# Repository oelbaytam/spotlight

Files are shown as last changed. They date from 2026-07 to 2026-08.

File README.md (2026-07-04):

# Spotlight

## What does it even do?
Spotlight is an [MQTT](https://learn.sparkfun.com/tutorials/introduction-to-mqtt/all) activated semi-high power LED (3.3-3.6V @715mA). It connects to MQTT Brokers (stay tuned for an MQTT discord bot!!) and uses the signal recieved to enable a PWM output to the LED. If I get it working correctly then there will be an enclosure with a way to focus the beam and some additional lenses to project imagery onto your wall or ceiling (think Bat-Signal). There are no physical inputs on the device so this is not a lamp.

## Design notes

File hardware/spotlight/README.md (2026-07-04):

# The Spotlight Hardware

Spotlight is my first attempt at SMD soldering, PCB design, Circuitry implementing an IC, and many other smaller things, so bear with any mistakes I make and feel free to contribute if you have hardware knowledge! \
(Make sure you teach me something if you submit a PR >:] )

## The Schematic and PCB
##### Fraud at a glance?
Schematic

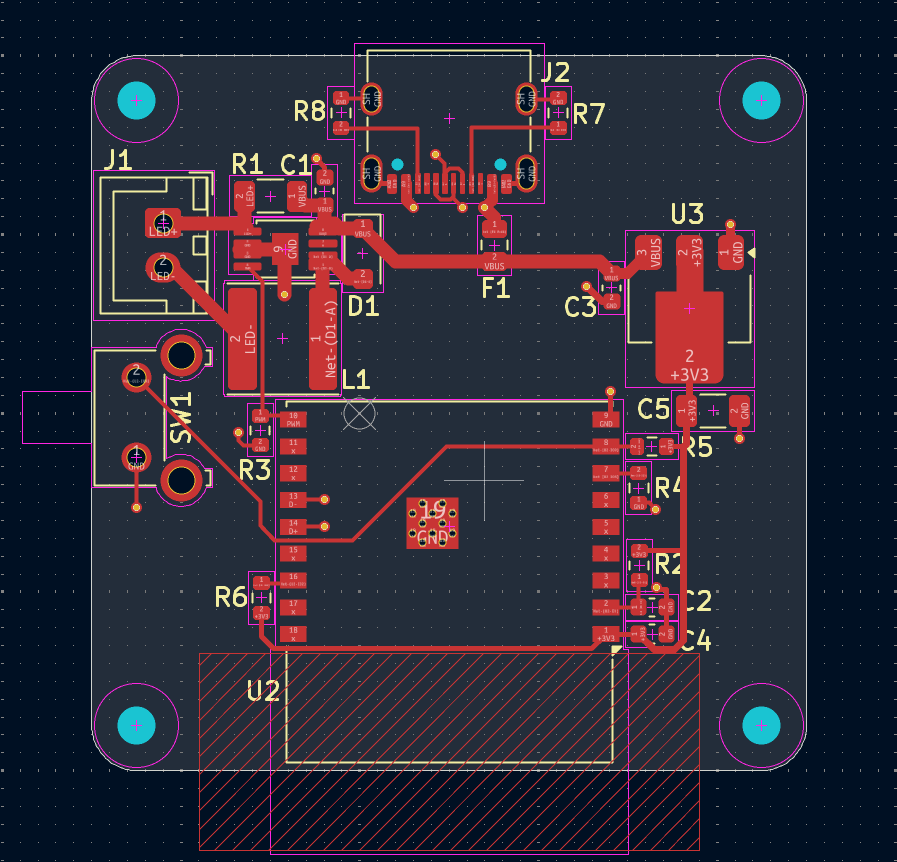
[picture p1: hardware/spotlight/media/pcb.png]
PCB


### The ICs
- AL8841MP-13 \
  A buck converter stepping down the 5V input to ~714mA constant current configured by the 0.14Ohm sense resistor. The LED I am using is 5W and expects 3.6V at 1.2A but in my testing it was plenty bright at 700mA@3.3V so I decided that it will live its life at 3W (heatsinks really drove up the price per unit).
- AMS1117-3.3 \
  LDO regulator that provides 3.3V to the MCU.
- ESP32-C3-WROOM-02-N4 \
  Before its a hardware project this was initially an embedded project so I could learn RTOS, MQTT, and the ESP-IDF development framework! I went with the WROOM because I only planned on using one GPIO pin. The C3 MINI was a bit cheaper but had a lot of much smaller pads that I wasn't confident I could reflow. (Probably could've added some extra pins but I didn't wanna overcomplicate any more.)

### The Cool Image on the Back?!
The picture is an item icon in DEADLOCK (I <3 Deadlock) called [Boundless Spirit](https://deadlock.wiki/Boundless_Spirit). It has nothing to do with the project, just a cool stamp I snatched. I put it through some image dithering so that it can work with the silkscreen, when I get the first PCBs in I will put a picture of it to show the real world result.

# Assembling the device
I don't know yet, but I have a plan that I will share with anyone who is new so assembly can be easy and cheap, I am pinching as many pennies as possible with this project. (Possibly will make a video?)

### Parts List

As of now, to get flashbanged, all you need is:
- The materials in the BOM (in the ./production folder but I would export it yourself)
- 3.3V LED that wont die taking 750mA (technically the size doesn't matter yet since I don't have an enclosure made.)
- JST XH-2 connector with a cable
- a Heatsink for the LED, I am going to use a 40x40x11mm heatsink. 
I am going to put my bead LED on a little star aluminum PCB to make my life easier and to make heat transfer to the heatsink better.

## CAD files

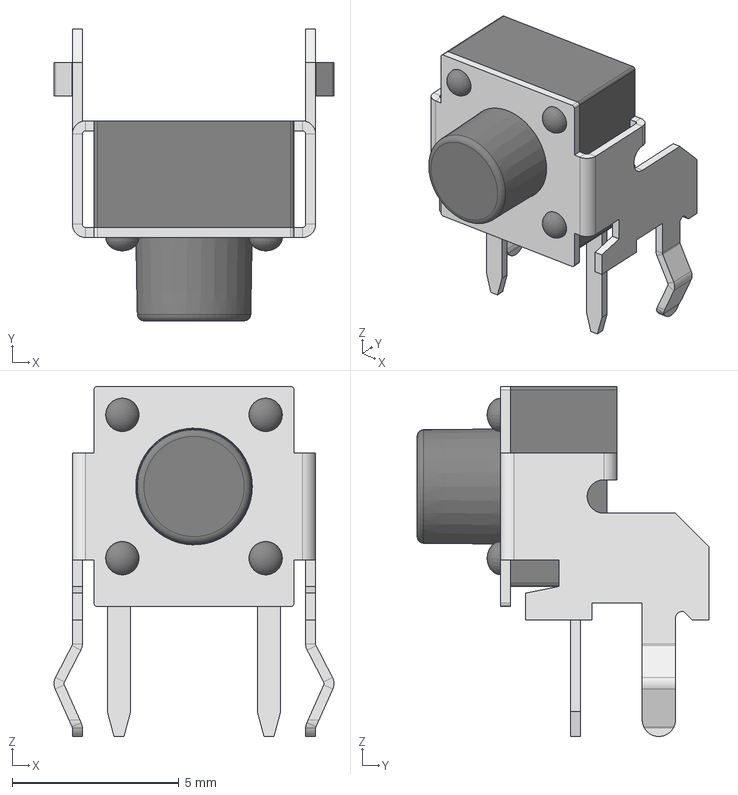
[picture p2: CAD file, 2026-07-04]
hardware/spotlight/footprint_models/TS6-THT-RA_H-6.0.step
8.40 x 8.75 x 10.5 mm

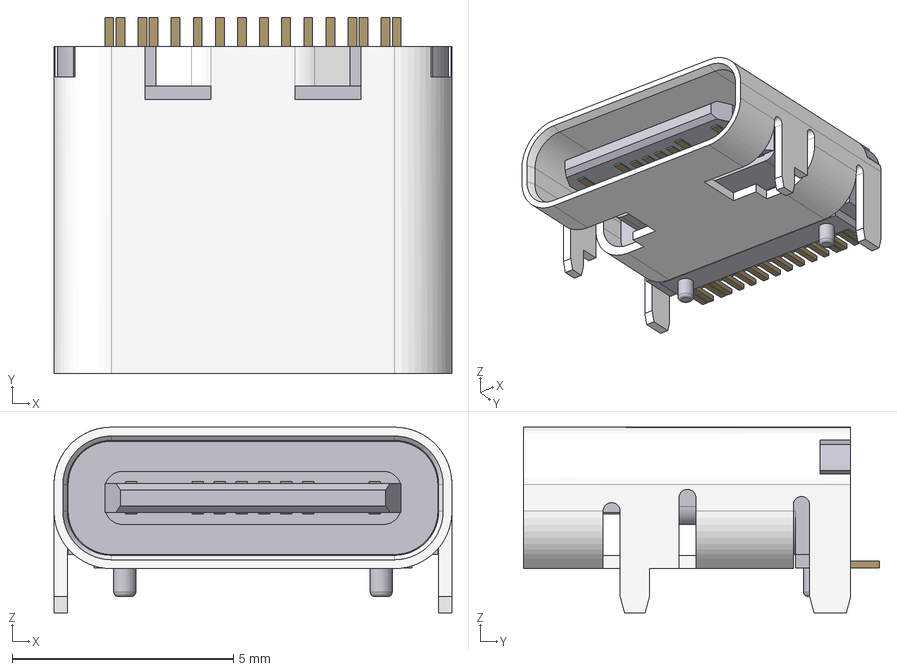
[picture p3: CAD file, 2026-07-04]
hardware/spotlight/footprint_models/usb-c_16pins_vertical.step
9.00 x 8.05 x 4.20 mm
tongue
shield
contact_001
contact_002
contact_003
contact_004
contact_court_001
contact_court_002
contact_court_003
contact_court_004
contact_005
contact_006
contact_007
contact_008
contact_court_005
contact_court_006
contact_court_007
contact_court_008
pin_001
pin_002
pin_003
pin_004
pin_005
pin_006
pin_007
pin_008
pin_009
pin_010
pin_011
pin_012
pin_013
pin_014
pin_015
pin_016

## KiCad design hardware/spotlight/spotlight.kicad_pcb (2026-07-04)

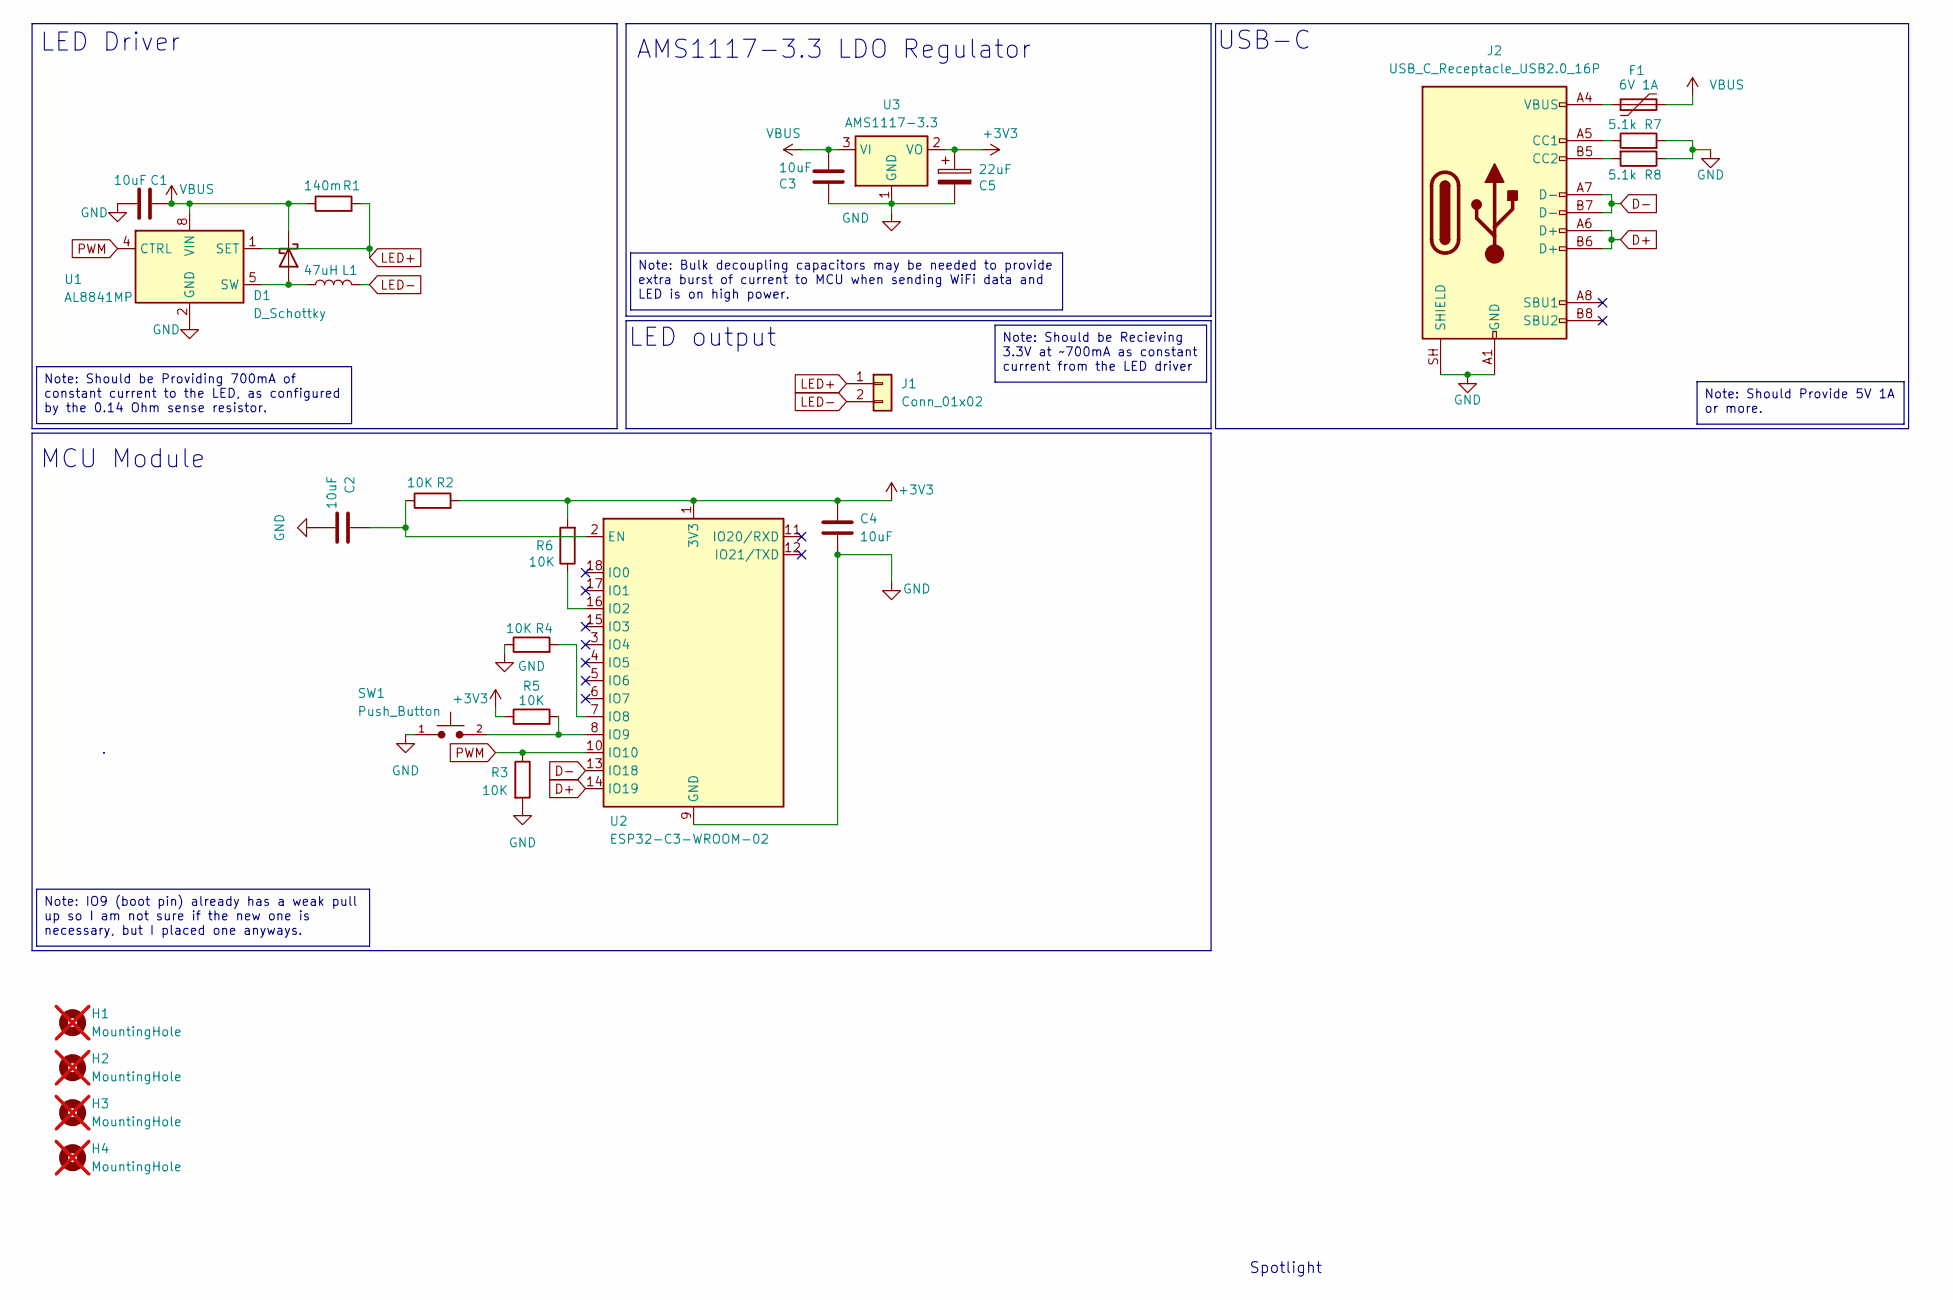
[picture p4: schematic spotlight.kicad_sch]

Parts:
C1, C2, C3, C4: 10uF; C_0603_1608Metric
C5: 22uF; C_1206_3216Metric
D1: D_Schottky; D_SOD-123F
F1: 6V 1A; R_0805_2012Metric
H1, H2, H3, H4: MountingHole; MountingHole_2.1mm; not fitted
J1: Conn_01x02; JST_XH_B2B-XH-A_1x02_P2.50mm_Vertical
J2: USB_C_Receptacle_USB2.0_16P; USB_C_Receptacle_XKB_U262-16XN-4BVC11
L1: 47uH; L_Chilisin_BWVS00606020
R1: 140m; R_1206_3216Metric
R2, R3, R4, R5, R6: 10K; R_0603_1608Metric
R7, R8: 5.1k; R_0603_1608Metric
SW1: Push_Button; SW_SPST_Omron_B3F-315x_Angled
U1: AL8841MP; MSOP-8-1EP_3x3mm_P0.65mm_EP1.5x1.8mm
U2: ESP32-C3-WROOM-02
U3: AMS1117-3.3; SOT-223-3_TabPin2

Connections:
+3V3: C4.1, C5.1, R2.2, R5.1, R6.2, U2.1 (3V3), U3.2 (VO)
D+: J2.A6 (D+), J2.B6 (D+), U2.14 (IO19)
D-: J2.A7 (D-), J2.B7 (D-), U2.13 (IO18)
GND: C1.2, C2.2, C3.2, C4.2, C5.2, J2.A1 (GND), J2.A12 (GND), J2.B1 (GND), J2.B12 (GND), J2.SH (SHIELD), R3.2, R4.1, R7.2, R8.1, SW1.1, U1.2 (GND), U1.3 (GND), U1.9 (GND), U2.9 (GND), U2.19 (GND), U3.1 (GND)
LED+: J1.1, R1.2, U1.1 (SET)
LED-: J1.2, L1.2
unnamed: D1.2 (A), L1.1, U1.5 (SW), U1.6 (SW)
unnamed: F1.1, J2.A4 (VBUS), J2.A9 (VBUS), J2.B4 (VBUS), J2.B9 (VBUS)
unnamed: J2.A5 (CC1), R7.1
unnamed: J2.B5 (CC2), R8.2
unnamed: C2.1, R2.1, U2.2 (EN)
unnamed: R6.1, U2.16 (IO2)
unnamed: R4.2, U2.7 (IO8)
unnamed: R5.2, SW1.2, U2.8 (IO9)
PWM: R3.1, U1.4 (CTRL), U2.10 (IO10)
VBUS: C1.1, C3.1, D1.1 (K), F1.2, R1.1, U1.8 (VIN), U3.3 (VI)

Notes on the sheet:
LED output
AMS1117-3.3 LDO Regulator
MCU Module
Spotlight
USB-C
LED Driver
Note: Bulk decoupling capacitors may be needed to provide extra burst of current to MCU when sending WiFi data and LED is on high power.
Note: IO9 (boot pin) already has a weak pull up so I am not sure if the new one is necessary, but I placed one anyways.
Note: Should be Providing 700mA of constant current to the LED, as configured by the 0.14 Ohm sense resistor.
Note: Should Provide 5V 1A or more.
Note: Should be Recieving 3.3V at ~700mA as constant current from the LED driver

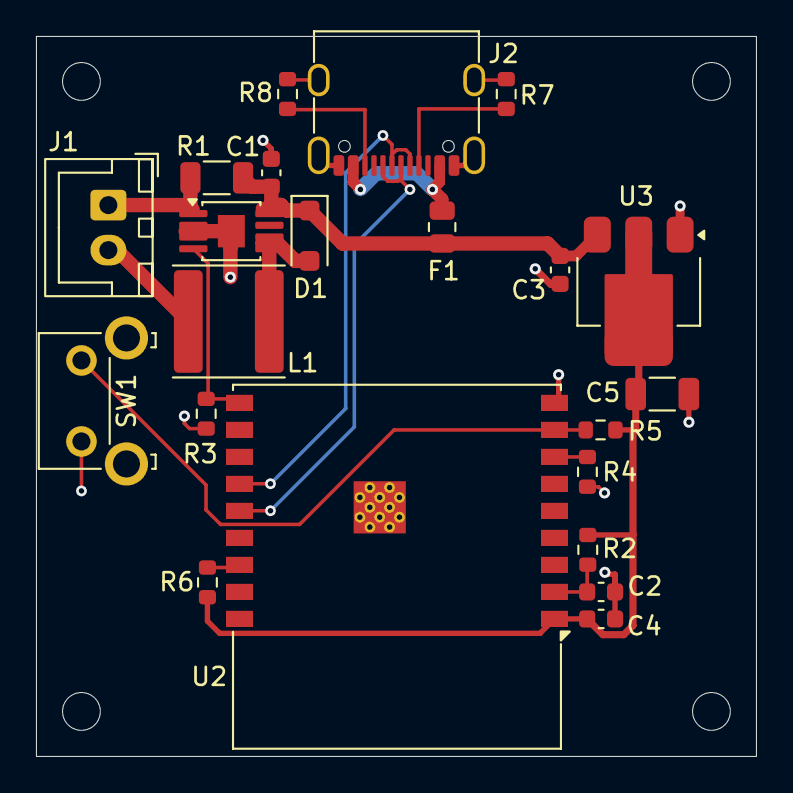
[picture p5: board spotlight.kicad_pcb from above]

Board: 2 copper layers, 40.0 x 40.0 mm, 26 parts (0 on the bottom side), 16 nets.

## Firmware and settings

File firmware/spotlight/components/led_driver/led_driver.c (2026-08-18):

#include "led_driver.h"
#include "driver/ledc.h"
#include "esp_log.h"
#include "freertos/projdefs.h"
#include "freertos/queue.h"
#include "freertos/task.h"
#include "hal/ledc_types.h"
#include "portmacro.h"
#include "sdkconfig.h"

// Hardware Configuration from Kconfig / sdkconfig
#define LEDC_MODE LEDC_LOW_SPEED_MODE
#define LEDC_TIMER ((ledc_timer_t)CONFIG_SPOTLIGHT_LEDC_TIMER)
#define LEDC_CHANNEL LEDC_CHANNEL_0
#define LEDC_GPIO (CONFIG_SPOTLIGHT_LED_GPIO)
#define LEDC_FREQ_HZ (CONFIG_SPOTLIGHT_PWM_FREQ_HZ)
#define LEDC_DUTY_RES LEDC_TIMER_10_BIT // 10-bit resolution (0..1023)
#define LEDC_MAX_DUTY                                                          \
  (2 << (LEDC_DUTY_RES - 1)) - 1 // 2**LEDC_DUTY_RES - 1 for max duty cycle
#define LEDC_SIGNAL_TIME_SEC 20  // Total signal duration in seconds
#define LEDC_SIGNAL_TIME_MS LEDC_SIGNAL_TIME_SEC * 1000

static const char *TAG = "LED_DRIVER";

// Global handle for the FreeRTOS Queue
QueueHandle_t xLedQueue = NULL;
static uint8_t active_priority = PRIORITY_LOW;

/**
 * Helper function to update LEDC duty cycle hardware.
 */
static void set_hardware_duty(uint32_t duty) {
  if (duty > LEDC_MAX_DUTY)
    duty = LEDC_MAX_DUTY;
  ledc_set_duty(LEDC_MODE, LEDC_CHANNEL, duty);
  ledc_update_duty(LEDC_MODE, LEDC_CHANNEL);
}

/**
 * TODO: Implement Queue Overflow Protection.
 *       Ensure that led_driver_send_cmd gracefully handles scenarios where the 
 *       MQTT client gets flooded with commands (e.g. 1000 msgs/sec), preventing 
 *       the FreeRTOS queue from overflowing or dropping high priority alerts.
 */

/**
 * Takes an led_cmd_t type command and pushes it onto the LedQueue based on
 * priority.
 */
BaseType_t led_driver_send_cmd(const led_cmd_t *cmd) {
  if (xLedQueue == NULL) {
    ESP_LOGE(TAG, "Led command recieved with an uninitialized LedQueue");
    return pdFALSE;
  }
  led_cmd_t pending_cmd; // Temporary variable to hold the next command.
  bool queue_not_empty;
  queue_not_empty = (xQueuePeek(xLedQueue, &pending_cmd, 0) == pdTRUE);

  if (queue_not_empty && pending_cmd.priority <= cmd->priority) {
    xQueueSendToFront(xLedQueue, cmd,
                      pdMS_TO_TICKS(10)); // arbitrary 10ms timeout
  } else {
    xQueueSendToBack(xLedQueue, cmd, pdMS_TO_TICKS(10));
  }
  return pdTRUE;
}

/**
 * Returns true if next command in xLedQueue is a higher priority than the
 * currently running priority. Returns false otherwise.
 */
static bool check_for_preemption(void) {
  led_cmd_t pending_cmd;
  bool queue_not_empty;
  queue_not_empty = (xQueuePeek(xLedQueue, &pending_cmd, 0) == pdTRUE);
  if (queue_not_empty && pending_cmd.priority >= active_priority) {
    ESP_LOGI(TAG,
             "Overriding current command due to new higher priority command");
    return true;
  }
  return false;
}

/**
 * Delays for wait_ms while constantly checking for preempting commands.
 * By polling the queue every 20ms, we guarantee immediate responsiveness
 * without blocking the FreeRTOS scheduler.
 */
static bool wait_with_preemption(uint32_t wait_ms) {
  uint32_t elapsed = 0;
  uint32_t step = 20; // 20ms polling interval
  while (elapsed < wait_ms) {
    if (check_for_preemption()) {
      return true; // A new, higher/equal priority command has arrived
    }
    vTaskDelay(pdMS_TO_TICKS(step));
    elapsed += step;
  }
  return false;
}

/**
 * Main LED Driver Task
 */
static void led_task(void *pvParameters) {
  led_cmd_t current_cmd;

  while (1) {
    xQueueReceive(xLedQueue, &current_cmd, portMAX_DELAY);
    active_priority = current_cmd.priority;
    
    // Safety check: prevent divide-by-zero if period wasn't set
    uint32_t period = current_cmd.period_ms > 0 ? current_cmd.period_ms : 1000;

    switch (current_cmd.action) {

    case LED_ACTION_ON:
      ESP_LOGI(TAG, "Led turning on for %ds", LEDC_SIGNAL_TIME_SEC);
      set_hardware_duty(LEDC_MAX_DUTY);
      wait_with_preemption(LEDC_SIGNAL_TIME_MS);
      set_hardware_duty(0);
      break;

    case LED_ACTION_OFF:
      ESP_LOGI(TAG, "Led turning off");
      set_hardware_duty(0);
      break;

    case LED_ACTION_SET_DUTY:
      ESP_LOGI(TAG, "Led being set to %d for %ds", current_cmd.duty, LEDC_SIGNAL_TIME_SEC);
      set_hardware_duty(current_cmd.duty);
      wait_with_preemption(LEDC_SIGNAL_TIME_MS);
      set_hardware_duty(0);
      break;

    case LED_ACTION_FLASH:
      ESP_LOGI(TAG, "Flashing led for %ds at duty %d", LEDC_SIGNAL_TIME_SEC, current_cmd.duty);
      int flash_cycles = LEDC_SIGNAL_TIME_MS / period;
      for (int i = 0; i < flash_cycles; i++) {
        // ON Phase
        set_hardware_duty(current_cmd.duty);
        if (wait_with_preemption(period / 2)) break;
        
        // OFF Phase
        set_hardware_duty(0);
        if (wait_with_preemption(period / 2)) break;
      }
      set_hardware_duty(0);
      break;

    case LED_ACTION_PULSE:
      ESP_LOGI(TAG, "Pulsing led for %ds to duty %d", LEDC_SIGNAL_TIME_SEC, current_cmd.duty);
      int pulse_cycles = LEDC_SIGNAL_TIME_MS / period;
      for (int i = 0; i < pulse_cycles; i++) {
        // Fade UP
        ledc_set_fade_with_time(LEDC_MODE, LEDC_CHANNEL, current_cmd.duty, period / 2);
        ledc_fade_start(LEDC_MODE, LEDC_CHANNEL, LEDC_FADE_NO_WAIT);
        if (wait_with_preemption(period / 2)) break;

        // Fade DOWN
        ledc_set_fade_with_time(LEDC_MODE, LEDC_CHANNEL, 0, period / 2);
        ledc_fade_start(LEDC_MODE, LEDC_CHANNEL, LEDC_FADE_NO_WAIT);
        if (wait_with_preemption(period / 2)) break;
      }
      set_hardware_duty(0);
      break;
    }
    
    // Tiny sleep to allow context switching before reading next item
    vTaskDelay(pdMS_TO_TICKS(10));
    active_priority = PRIORITY_LOW;
  }
}

/**
 * Initializes the LEDC timers and fade handlers, and initializes the driver
 * task.
 */
void led_driver_init(void) {
  // Hardware Setup: LEDC Timer
  ledc_timer_config_t ledc_timer = {.duty_resolution = LEDC_DUTY_RES,
                                    .freq_hz = LEDC_FREQ_HZ,
                                    .speed_mode = LEDC_MODE,
                                    .timer_num = LEDC_TIMER,
                                    .clk_cfg = LEDC_AUTO_CLK};
  ledc_timer_config(&ledc_timer);

  // Hardware Setup: LEDC Channel
  ledc_channel_config_t ledc_channel = {.channel = LEDC_CHANNEL,
                                        .duty = 0,
                                        .gpio_num = LEDC_GPIO,
                                        .speed_mode = LEDC_MODE,
                                        .hpoint = 0,
                                        .timer_sel = LEDC_TIMER};
  ledc_channel_config(&ledc_channel);

  ledc_fade_func_install(0);

  xLedQueue = xQueueCreate(CONFIG_SPOTLIGHT_QUEUE_SIZE, sizeof(led_cmd_t));
  xTaskCreate(led_task, "led_task", 4096, NULL, 5, NULL);

  ESP_LOGI(TAG, "LED Driver hardware initialized on GPIO %d @ %d Hz", LEDC_GPIO,
           LEDC_FREQ_HZ);
}

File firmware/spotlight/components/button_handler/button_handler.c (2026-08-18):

#include "button_handler.h"
#include "driver/gpio.h"
#include "esp_log.h"
#include "freertos/FreeRTOS.h"
#include "freertos/projdefs.h"
#include "freertos/task.h"
#include "led_driver.h"
#include "sdkconfig.h"
#include <stdio.h>

#define BUTTON_GPIO (CONFIG_SPOTLIGHT_BUTTON_GPIO)
#define LONG_PRESS_HOLD_MS (CONFIG_SPOTLIGHT_BUTTON_LONG_PRESS_MS)

static const char *TAG = "BUTTON_HANDLER";
static button_long_press_cb_t s_long_press_cb = NULL;

/**
 * TODO: Convert Button Handler to use hardware IRQ (Interrupt Request).
 *       The current polling method using vTaskDelay can miss rapid button presses 
 *       if the CPU is busy with high-priority LED commands. Transition to 
 *       gpio_install_isr_service() and use a FreeRTOS Queue to prevent blocking.
 */

/**
 * Button handler task
 * Checks for a pulldown on the button pin, records time.
 * if time > 100ms and time < LONG_PRESS_HOLD_MS:
 *    a stop override is sent to the LED driver
 * if time > LONG_PRESS_HOLD_MS:
 *    a callback function is called that handles provisioning
 * if time < 100ms:
 *    it is considered a false input and nothing happens.
 */
static void button_task(void *pvParameters) {

  while (1) {
    if (gpio_get_level(BUTTON_GPIO) == 0) {
      int start_ticks = xTaskGetTickCount();
      int elapsed_ms = 0;
      while (gpio_get_level(BUTTON_GPIO) == 0) {
        ESP_LOGI(TAG, "Active Press, current duration = %d",
                 pdTICKS_TO_MS(xTaskGetTickCount() - start_ticks));
        vTaskDelay(pdMS_TO_TICKS(20));
      }
      elapsed_ms = pdTICKS_TO_MS(xTaskGetTickCount() - start_ticks);
      if (elapsed_ms >= LONG_PRESS_HOLD_MS) {
        ESP_LOGI(TAG, "Long press detected! Triggering provisioning");
        if (s_long_press_cb != NULL) {
          s_long_press_cb();
        }
      } else if (elapsed_ms >= 80) {
        ESP_LOGI(TAG, "Short press detected!");
        led_cmd_t command = {LED_ACTION_OFF, PRIORITY_OVERRIDE, 0, 0};
        led_driver_send_cmd(&command);
      } else {
        ESP_LOGI(TAG, "A %d ms press was ignored for being under 80ms",
                 elapsed_ms);
      }
    }
    // Dummy delay so task doesn't trigger Watchdog timer
    vTaskDelay(pdMS_TO_TICKS(20));
  }
}

/**
 * Initializes the task, gpio pin, and long press callback function.
 */
void button_handler_init(button_long_press_cb_t long_press_cb) {

  gpio_config_t io_conf = {(1ULL << BUTTON_GPIO), GPIO_MODE_INPUT,
                           GPIO_PULLUP_ENABLE, GPIO_PULLDOWN_DISABLE,
                           GPIO_INTR_DISABLE};

  gpio_config(&io_conf);
  s_long_press_cb = long_press_cb;
  xTaskCreate(button_task, "Button Handler Task", 4096, NULL, 5, NULL);

  ESP_LOGI(TAG, "Button Handler initialized on GPIO %d (Long Hold = %d ms)",
           BUTTON_GPIO, LONG_PRESS_HOLD_MS);
}

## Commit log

2026-06-22 Initialized ESP-IDF Firmware and KiCAD Project with Core IC's and Outputs
    [CONN-TH_XH-2A_C722856.step, MQTT LED.kicad_pcb, MQTT LED.kicad_sch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]
2026-06-24 v1 of the board?
    [C0402_L1.0-W0.5-H0.5.step, C0805_L2.0-W1.3-H1.3.step, IND-SMD_L8.0-W8.0_ESN8040.step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]
2026-06-24 PCB updates
    [MQTT LED.kicad_sch]
2026-06-28 added todos
    [MQTT LED.kicad_pcb, MQTT LED.kicad_sch]
2026-06-28 Switched to USB programming and ESP32-C3 module
    [MQTT LED.kicad_pcb, MQTT LED.kicad_sch]
2026-07-04 Added some models, images, major revisions to board and parts, README.md for hardware and root
    [C0402_L1.0-W0.5-H0.5.step, C0805_L2.0-W1.3-H1.3.step, CONN-TH_XH-2A_C722856.step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]
2026-07-21 Pulsing LED firmware to test the hardware, it works!
2026-08-14 Implemented the button handler and the led driver components
